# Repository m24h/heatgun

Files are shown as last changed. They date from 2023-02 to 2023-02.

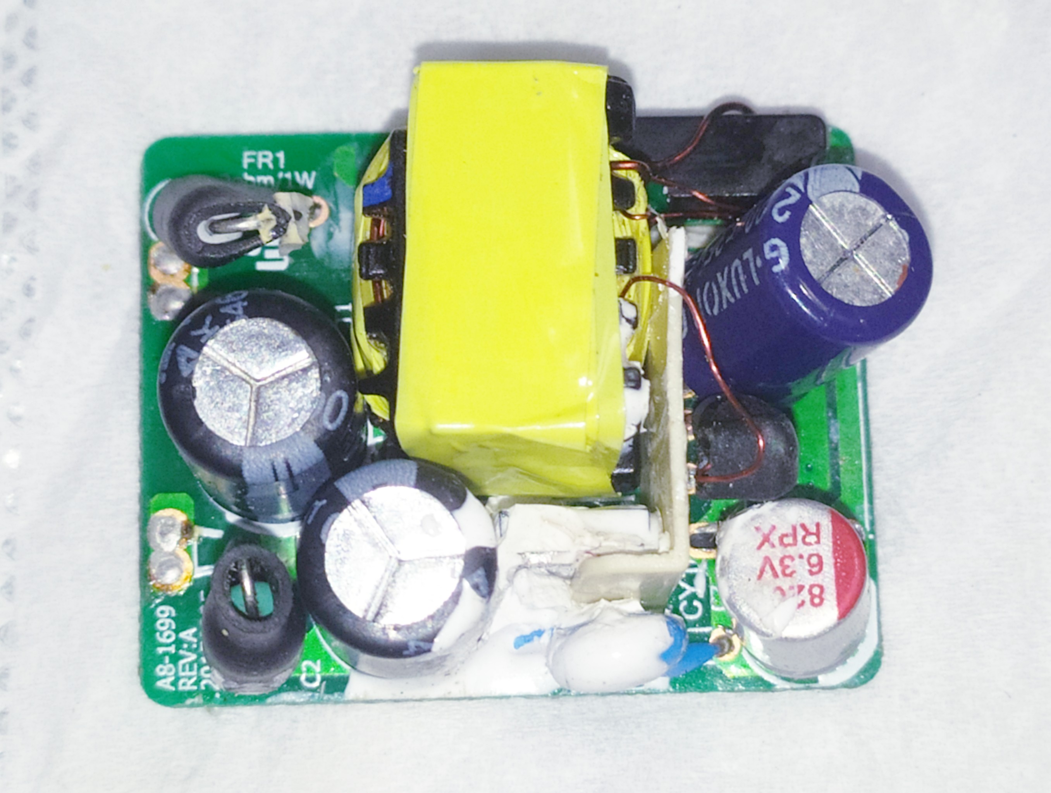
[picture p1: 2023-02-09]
practice/power-top.jpg

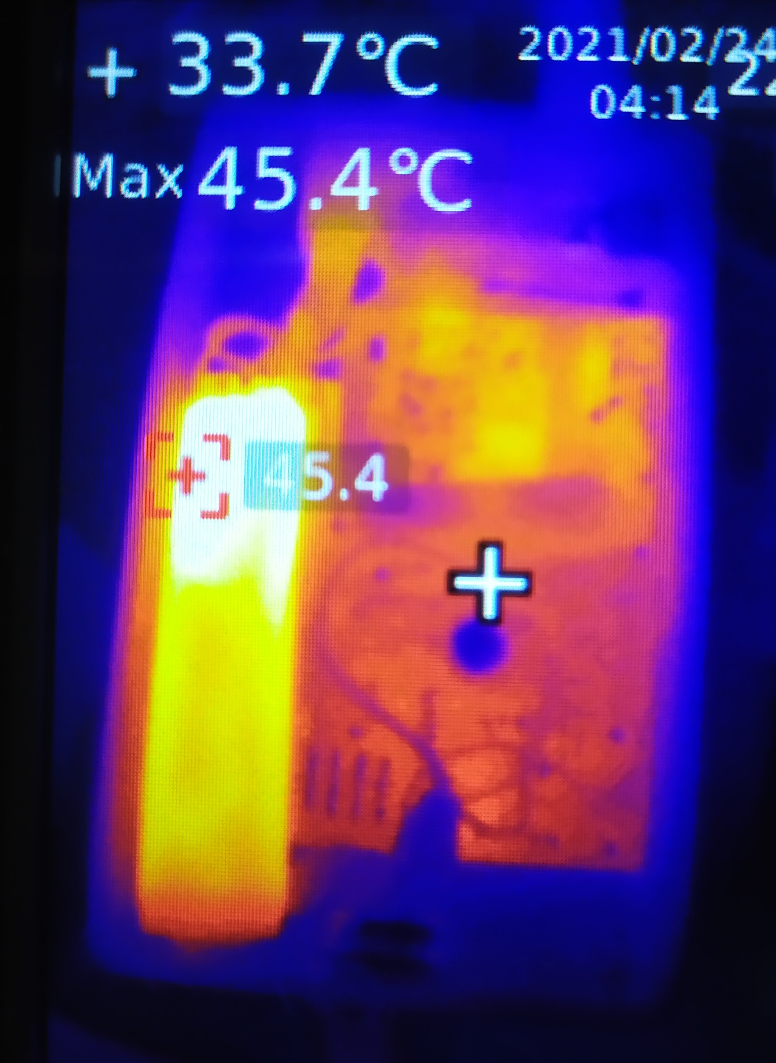
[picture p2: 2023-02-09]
practice/heat-sink.jpg

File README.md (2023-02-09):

# heatgun
A small hot air station for soldering, using type-858 heat gun as handle, STC8G1k17 as MCU, copper wire resistor for cold junction compensation.

##Features:

* Small, cheap, esay to make
* With cold junction compensation
* Software correction 
* Compatible with most type-858 handle
* Settings can be remembered
* PID temperature control

## Burning/Downloading

This program is only for MCU STC8G1K17-16pin, compiled and linked by SDCC 4.2.0

It must be burned at following scheme:

* Internal IRC Freq. : 22.1184MHz (as same as specified in def.h)
* User EEPROM size : 2k (as same as specified in def.h)
* Low-voltage reset : Enable
* Reset pin used as I/O port : Yes
* Hardware enable WDT : Disable (I will use software enable it)
* Add a reset code in front of ID : Yes (it will adds Band-Gap voltage reference)
* Erase all EEPROM data : Yes
* Fill data to space area : 0XFF

## About cold junction compensation for the thermocouple in the handle

I add a coper wire wound resistor (nearly 13.5 OHM) in the handle, in series with the thermocouple, for cold junction compensation at a suitable bias current.
And my software will do some corrections/calculations for getting accurate temperature from the thermocouple.

But if the connector between your handle and main controller board is not in good contact, this will introduce jitter in the temperature values.

In this case, the coper wire resistor can be totally removed, and several components (R5,R13) on the PCB can also be removed,
and several parameters inside the program can also be adjusted (set g_ana_pk=0 at main.c). 

In fact, the temperature rising of the thermocouple's cold junction within the handle, is not obvious. 
It is not really necessary to do cold junction compensation, and there are already an offset compensation. 
As long as you press and hold the button at startup, you can enter room temperature parameter.
In most cases, this is enough.

## About offset adjustment for AMP (LM321)

LM321 used in my circuit is not a precision OP-AMP and there may be large input offset voltage (normally within a few millivolts).
Because of the cold junction compensation circuit, its negative offset can be ignored, 
but if the positive offset is too large, it may be necessary to add resistor (R14) to the circuit for keeping the output in the linear range.

If you remove the cold junction compensation resistor in the handle, and the negative offset cannot be ignored, 
I suggest that you still need to add one resistor in series, however, this resistor can take a larger value, 
and at the same time increase the values of R5 and R13 in the circuit, 
so that there will be no obvious jitter caused by the connector contact resistor.

Also do not adjust the offset to 0, keep an output of OP-AMP hundreds of millivolts at least.

## About the gain of AMP (LM321)

LM321 is also not a rail-to-rail OP-AMP, especially since its high output is close to 1V away from the power voltage.

If the gain designed is too large, the temperature measurement range will be limited. 
With my current design, there is no problem with the range within 500 centidegrees, 
but if a larger range is needed, the gain needs to be reduced (change R8/R9) and the parameters (g_ana_gain at main.c) in program needs to be adjusted too.

## About power supply

The circuit requires 2 ways of power supply, a 5V for controller, another 24V for the fan (normally 24V 0.1xxA) in the handle.
I didn't include this in my design, you can use the finished product from other way, or modify an unused phone charger like me (10W required).

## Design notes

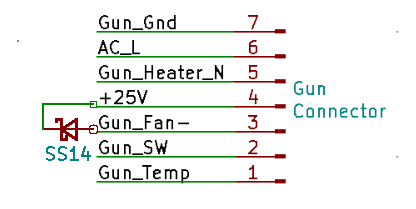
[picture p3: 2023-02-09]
circuit/gun_connector.png

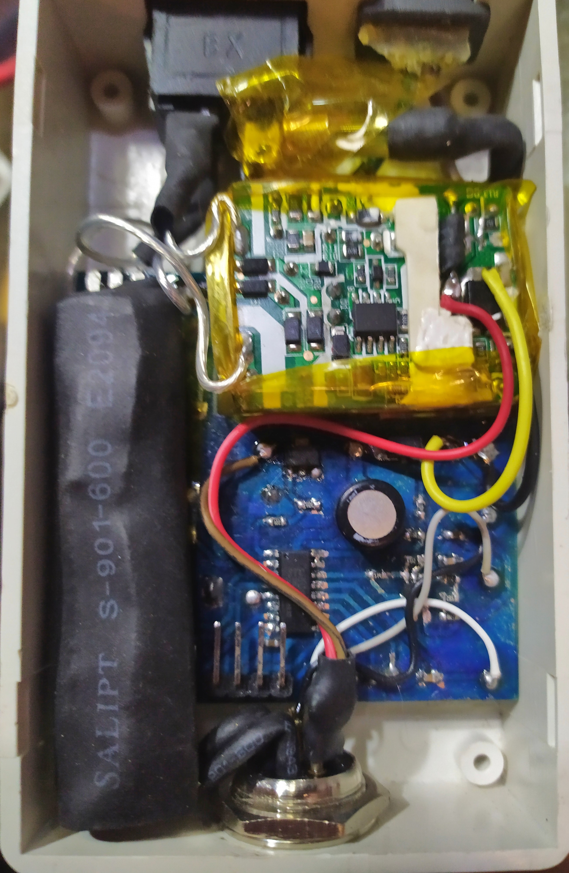
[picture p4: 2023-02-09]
practice/in-box.jpg

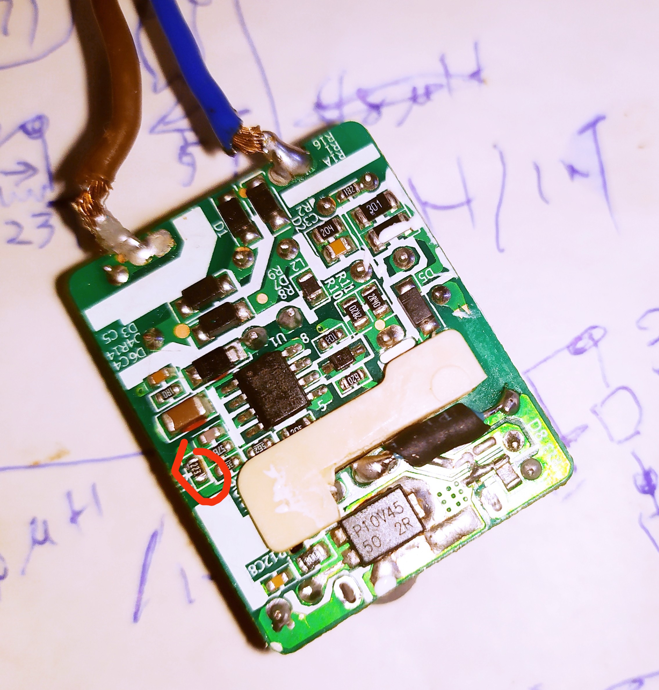
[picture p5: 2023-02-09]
practice/power-bottom.jpg

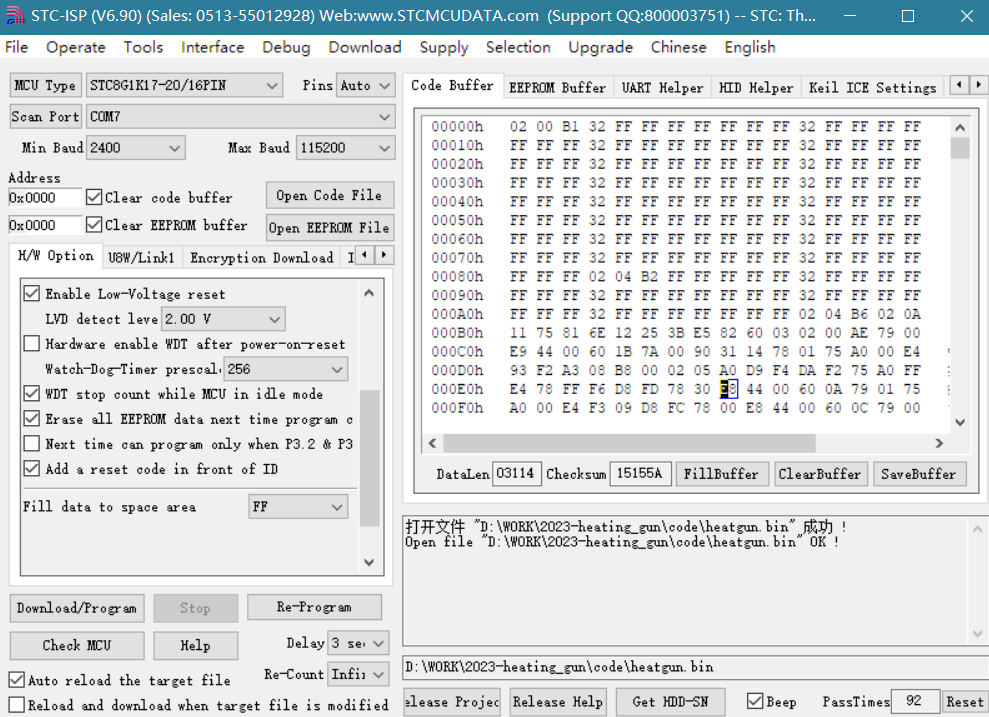
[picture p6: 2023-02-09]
practice/burn2.png

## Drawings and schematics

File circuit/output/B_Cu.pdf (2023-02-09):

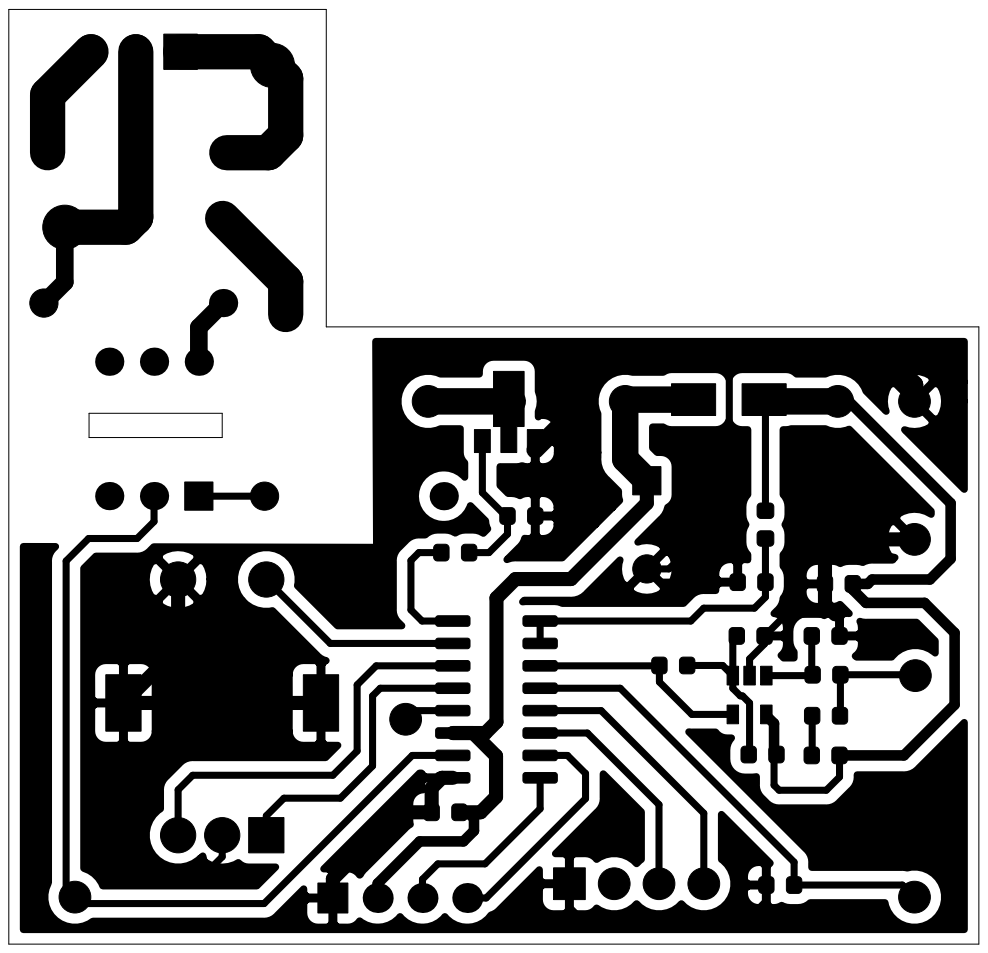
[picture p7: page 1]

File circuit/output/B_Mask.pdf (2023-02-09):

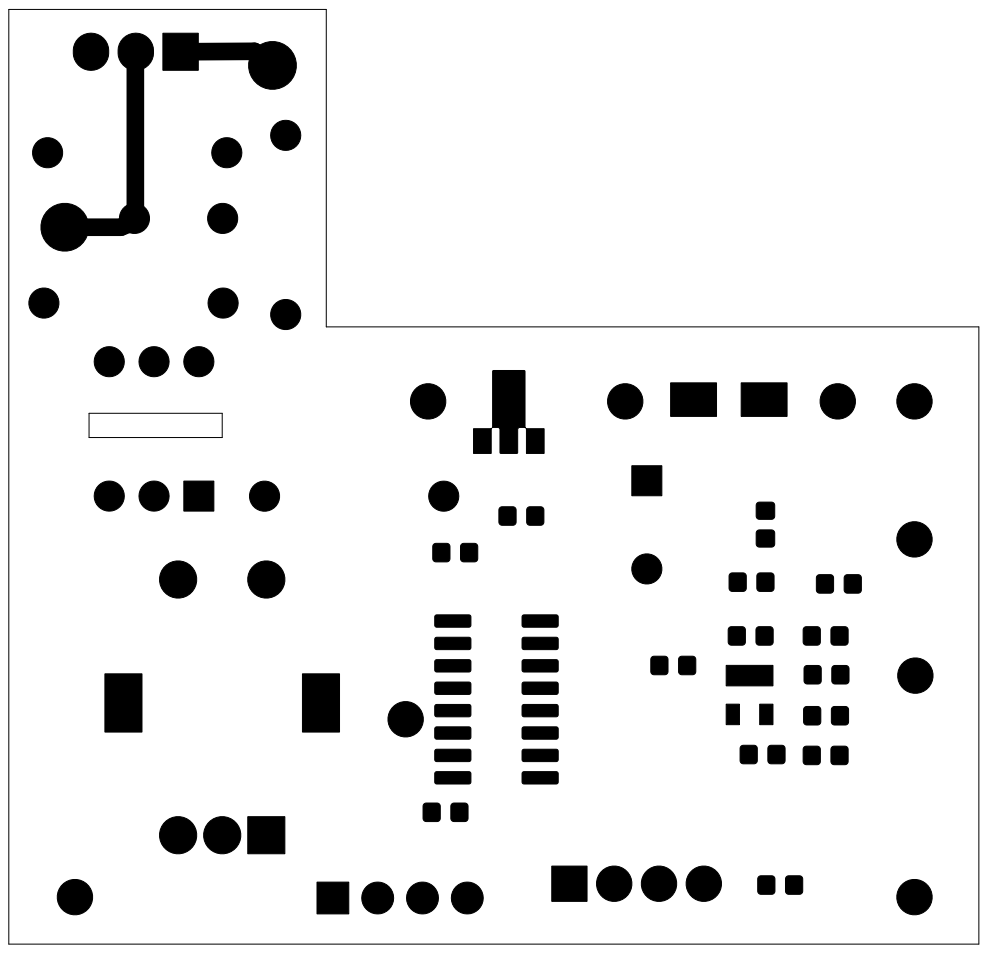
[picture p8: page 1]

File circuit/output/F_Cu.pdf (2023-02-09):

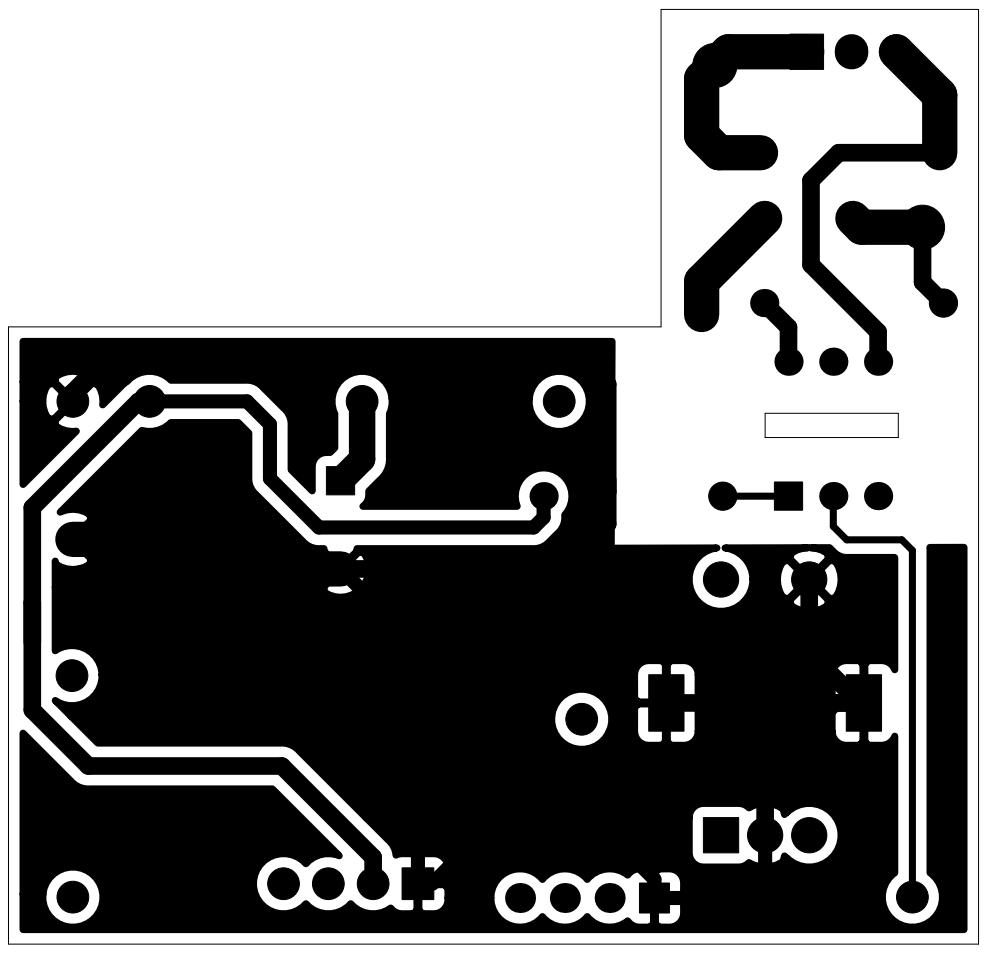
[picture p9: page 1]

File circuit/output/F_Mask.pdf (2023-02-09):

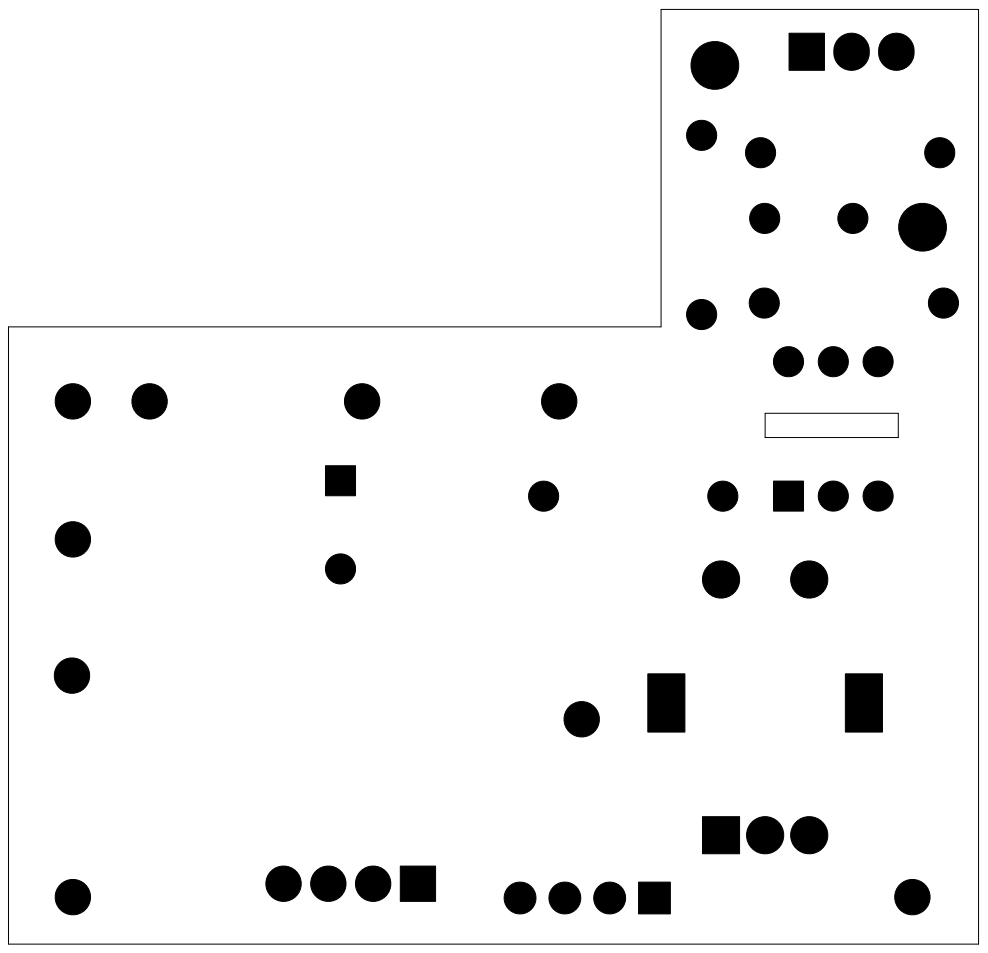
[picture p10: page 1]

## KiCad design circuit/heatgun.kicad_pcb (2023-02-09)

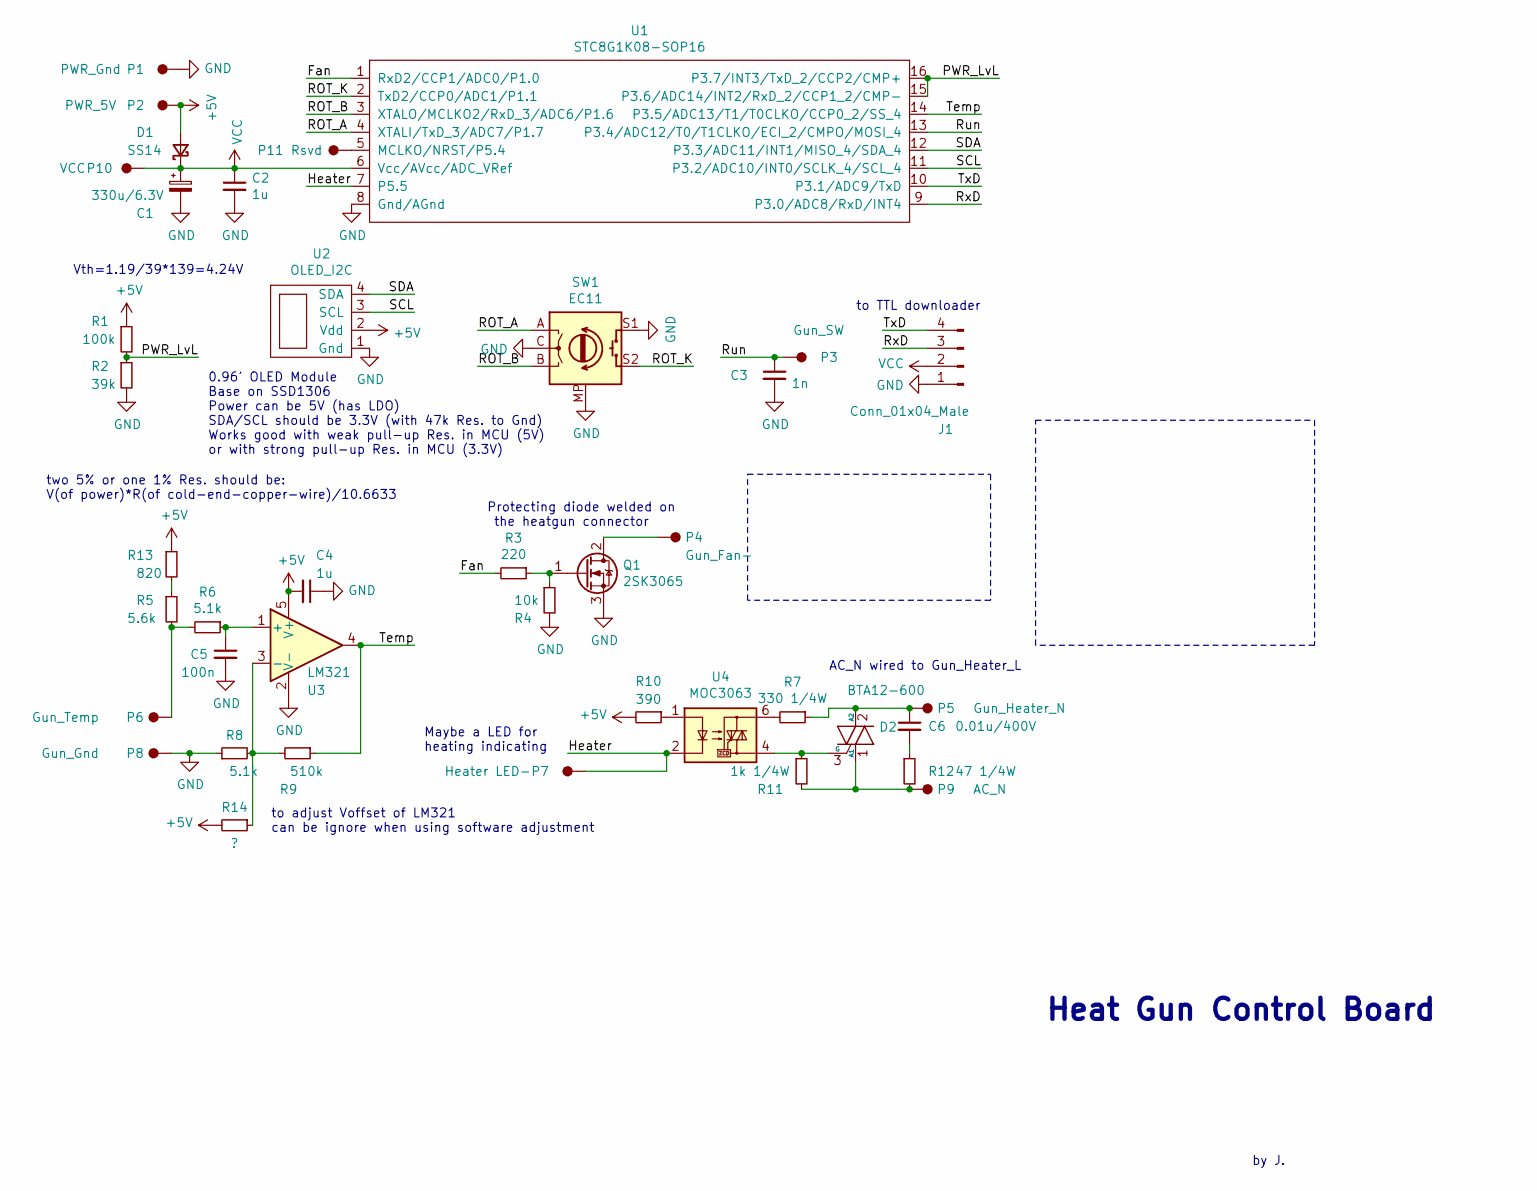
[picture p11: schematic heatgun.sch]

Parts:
C1: 330u/6.3V; CP_Radial_D8.0mm_P5.00mm
C2, C4: 1u; C_0603_1608Metric
C3: 1n; C_0603_1608Metric
C5: 100n; C_0603_1608Metric
C6: 0.01u/400V; C_Rect_L7.0mm_W2.5mm_P5.00mm
D1: SS14; D_SMA
D2: BTA12-600; TO-220-3_Vertical
J1: Conn_01x04_Male; PinHeader_1x04_P2.54mm_Vertical
P1: PWR_Gnd; Pad-1.8-h1
P2: PWR_5V; Pad-1.8-h1
P3: Gun_SW; Pad-1.8-h1
P4: Gun_Fan-; Pad-1.8-h1
P5: Gun_Heater_N; Pad-2.5-h1
P6: Gun_Temp; Pad-1.8-h1
P7: Heater LED-; Pad-1.8-h1
P8: Gun_Gnd; Pad-1.8-h1
P9: AC_N; Pad-2.5-h1
P10: VCC; Pad-1.8-h1
P11: Rsvd; Pad-1.8-h1
Q1: 2SK3065; SOT-89-3
R1: 100k; R_0603_1608Metric
R2: 39k; R_0603_1608Metric
R3: 220; R_0603_1608Metric
R4: 10k; R_0603_1608Metric
R5: 5.6k; R_0603_1608Metric
R6, R8: 5.1k; R_0603_1608Metric
R7: 330 1/4W; R_Axial_DIN0207_L6.3mm_D2.5mm_P10.16mm_Horizontal
R9: 510k; R_0603_1608Metric
R10: 390; R_Axial_DIN0207_L6.3mm_D2.5mm_P10.16mm_Horizontal
R11: 1k 1/4W; R_Axial_DIN0207_L6.3mm_D2.5mm_P10.16mm_Horizontal
R12: 47 1/4W; R_Axial_DIN0207_L6.3mm_D2.5mm_P10.16mm_Horizontal
R13: 820; R_0603_1608Metric
R14: ?; R_0603_1608Metric
SW1: EC11; RotaryEncoder_Alps_EC11E-Switch_Vertical_H20mm
U1: STC8G1K08-SOP16; SOIC-16_3.9x9.9mm_P1.27mm
U2: OLED_I2C; OLED-I2C-0.96-27.5X27.8
U3: LM321; SOT-23-5
U4: MOC3063; DIP-6_W7.62mm

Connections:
+5V: C4.2, D1.2 (A), P2.1, R1.1, R10.2, R13.1, R14.2, U2.2 (Vdd), U3.5 (V+)
/Fan: R3.2, U1.1 (RxD2/CCP1/ADC0/P1.0)
/Heater: P7.1, U1.7 (P5.5), U4.2
/PWR_LvL: R1.2, R2.1, U1.15 (P3.6/ADC14/INT2/RxD_2/CCP1_2/CMP-), U1.16 (P3.7/INT3/TxD_2/CCP2/CMP+)
/ROT_A: SW1.A, U1.4 (XTALI/TxD_3/ADC7/P1.7)
/ROT_B: SW1.B, U1.3 (XTALO/MCLKO2/RxD_3/ADC6/P1.6)
/ROT_K: SW1.S2, U1.2 (TxD2/CCP0/ADC1/P1.1)
/Run: C3.1, P3.1, U1.13 (P3.4/ADC12/T0/T1CLKO/ECI_2/CMPO/MOSI_4)
/RxD: J1.3, U1.9 (P3.0/ADC8/RxD/INT4)
/SCL: U1.11 (P3.2/ADC10/INT0/SCLK_4/SCL_4), U2.3 (SCL)
/SDA: U1.12 (P3.3/ADC11/INT1/MISO_4/SDA_4), U2.4 (SDA)
/Temp: R9.1, U1.14 (P3.5/ADC13/T1/T0CLKO/CCP0_2/SS_4), U3.4
/TxD: J1.4, U1.10 (P3.1/ADC9/TxD)
GND: C1.2, C2.2, C3.2, C4.1, C5.2, J1.1, P1.1, P8.1, Q1.3 (S), R2.2, R4.2, R8.1, SW1.C, SW1.MP, SW1.S1, U1.8 (Gnd/AGnd), U2.1 (Gnd), U3.2 (V-)
unnamed: C5.1, R6.1, U3.1 (+)
unnamed: C6.1, D2.2 (A2), P5.1, R7.1
unnamed: C6.2, R12.1
unnamed: D2.1 (A1), P9.1, R11.2, R12.2
unnamed: D2.3 (G), R11.1, U4.4
unnamed: P4.1, Q1.2 (D)
unnamed: P6.1, R5.2, R6.2
unnamed: P11.1, U1.5 (MCLKO/NRST/P5.4)
unnamed: Q1.1 (G), R3.1, R4.1
unnamed: R7.2, U4.6
unnamed: R10.1, U4.1
unnamed: R5.1, R13.2
unnamed: R8.2, R9.2, R14.1, U3.3 (-)
VCC: C1.1, C2.1, D1.1 (K), J1.2, P10.1, U1.6 (Vcc/AVcc/ADC_VRef)

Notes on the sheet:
Protecting diode welded on the heatgun connector
AC_N wired to Gun_Heater_L
to TTL downloader
0.96' OLED Module Base on SSD1306 Power can be 5V (has LDO) SDA/SCL should be 3.3V (with 47k Res. to Gnd) Works good with weak pull-up Res. in MCU (5V) or with strong pull-up Res. in MCU (3.3V)
Maybe a LED for heating indicating
Vth=1.19/39*139=4.24V
two 5% or one 1% Res. should be: V(of power)*R(of cold-end-copper-wire)/10.6633
to adjust Voffset of LM321 can be ignore when using software adjustment
Heat Gun Control Board
by J.

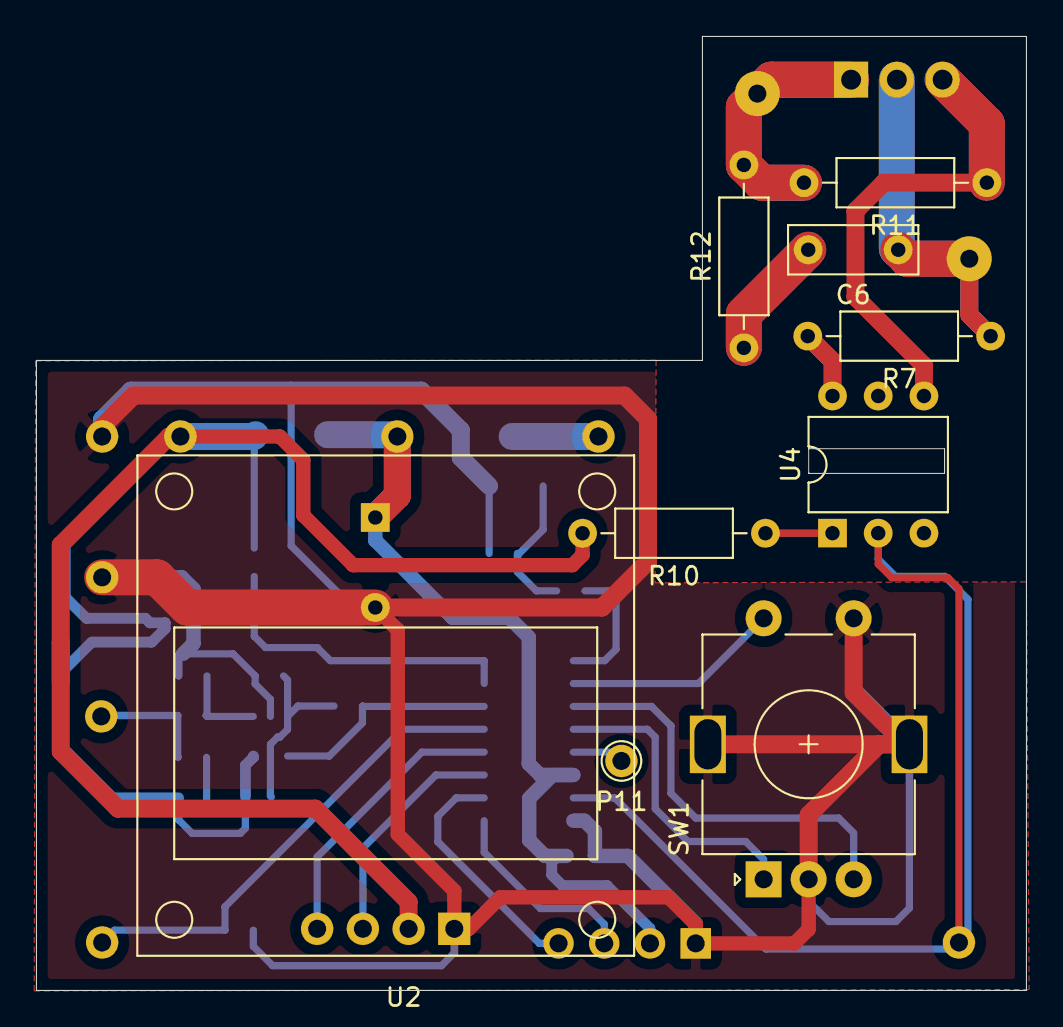
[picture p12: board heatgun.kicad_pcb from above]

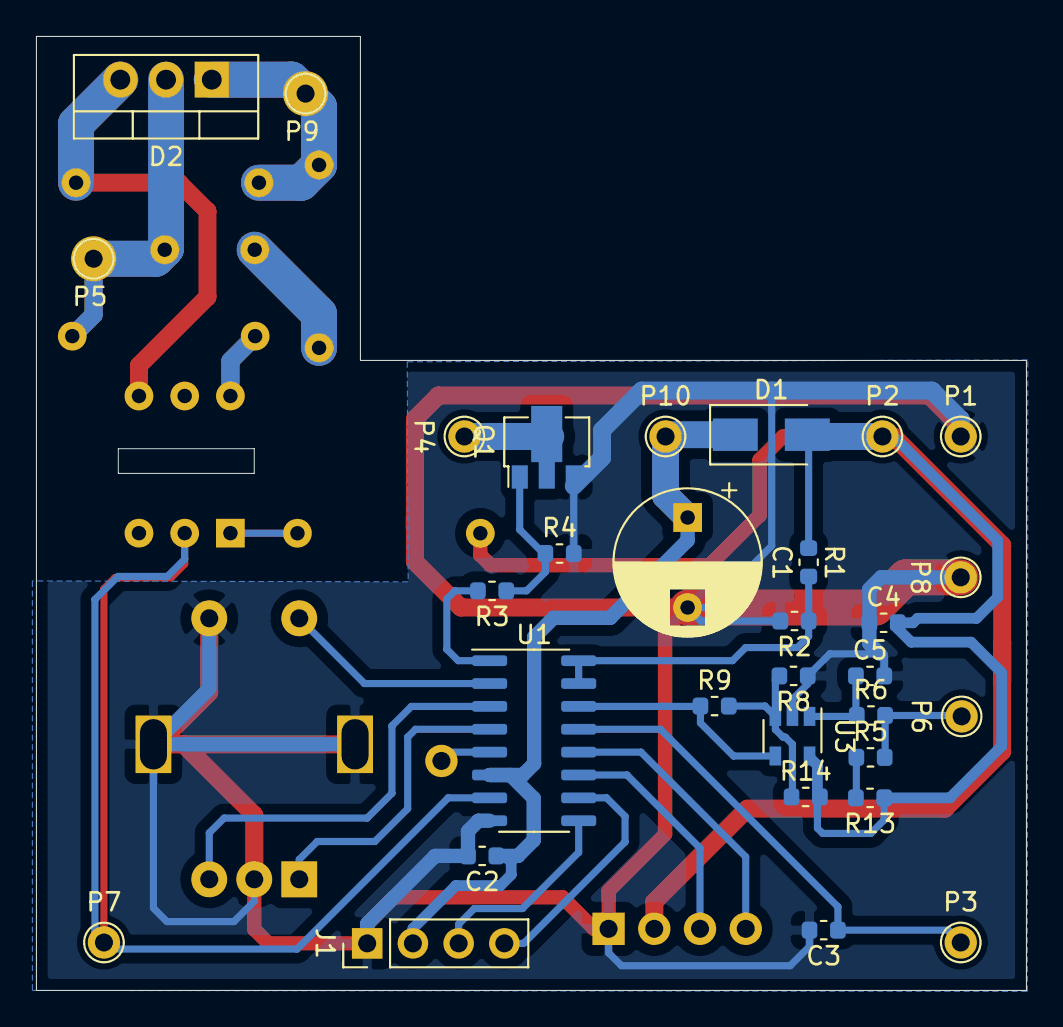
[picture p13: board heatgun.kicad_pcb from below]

Board: 2 copper layers, 55.0 x 53.0 mm, 40 parts (31 on the bottom side), 28 nets.

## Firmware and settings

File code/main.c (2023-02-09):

// Copyright 2003 m24h, see http://www.apache.org/licenses/LICENSE-2.0

#include	"def.h"
#include	"iic.h"
#include	"ssd1306.h"
#include      "ser.h"
#include	"fonts.h"
#include	"K.h"
#include	"key.h"
#include	"iap.h"
#include	"eeprom.h"
#include	"tools.h"

/*
	This program is for STC8G1K17-16pin
	MCU must be burned at following scheme:
		Internal IRC Freq. : 22.1184MHz (as same as specified in def.h)
		User EEPROM size : 2k (as same as specified in def.h)
		Low-voltage reset : Enable
		Reset pin used as I/O port : Yes
		Hardware enable WDT : Disable (I will use software enable it)
		Add a reset code in front of ID : Yes (it will adds Band-Gap voltage reference)
		Erase all EEPROM data : Yes
		Fill data to space area : 0XFF
	Calibration Data:
		They will be set at last flash page which is start from 0x4200 (or 0x600 at EEPROM address)
*/

#define DEBUG 1
#define TRACE  1

#define FREQ_IIC        200000   /* IIC frequency */
#define BAUDRATE     115200 /* serial baudrate */

#define TEMP_MIN  100  /* lowest temperature setting */
#define TEMP_MAX  500 /* highest temperature setting */
#define TEMP_COLD 25 /* init or default room temperature */
#define TEMP_TIMEOUT  10 /* in seconds,  if in temperature controlling mode, when timeout, it will be automatically back to blow controlling mode */
#define BLOW_LEVELS 16   /* levels of wind blowing control */
#define BLOW_PWM_MIN 50   /* 0-255 PWM setting when blowing setting level 0, this should be tested for another fan, don't make fan stop spinning  */
#define BLOW_STOP_TEMP 80 /* when temperature is cool-down to this, blowing can stop */
#define BLOW_START_TEMP 200 /* when temperature is higher than this, blowing must start to protect heating gun */

#define PID_KP	0.08  /* nearly 20 centigrades make full control */
#define PID_TI	200
#define PID_TD	8
#define PID_TF	2
#define PID_FALL	5   /* Enhance the control effect for temperature falling, which is always slower than rising */
#define PID_EDGE_TOP    4     /* use directly control instead of PID when temperature error is out of a range */
#define PID_EDGE_BTM   100     /* use directly control instead of PID when temperature error is out of a range */

#define ANA_GAIN 0.009901 /* gain of input to output of AMP 5.1k/(5.1k+510k), in design */
#define ANA_OFF   0.0              /* offset of AMP and residuals, in uV, 0 in design */
#define ANA_PK      0.002176  /* correction coefficient of power voltage, 14/(6420+14), in design */
#define ANA_PG     3.5641  /* gain of power voltage  to ADC input, (39+100)/39, in design */

// ADC Band-Gap reference
#define BG_REF_DEF	1190    /* default, will be used if loading from BG_REFL/BG_REFH fails */
__code __at(EEPROM_OFFSET+EEPROM_PAGE_SIZE*EEPROM_PAGES-8) u8 BG_REFL;  // get Band-Gap Ref. mV, need to enable "Add a reset code in front of ID" option before downloading using STC-ISP
__code __at(EEPROM_OFFSET+EEPROM_PAGE_SIZE*EEPROM_PAGES-9) u8 BG_REFH; // get Band-Gap Ref. mV, need to enable "Add a reset code in front of ID" option before downloading using STC-ISP

// my calibration data
__code __at(EEPROM_OFFSET+EEPROM_PAGE_SIZE*(EEPROM_PAGES-1)) 		u8 CALI_TAG;          // when CALI_XXX exists, it will be 0x55
__code __at(EEPROM_OFFSET+EEPROM_PAGE_SIZE*(EEPROM_PAGES-1)+2) 	u8 CALI_OFFSETH;  // add offset, in uV, signed
__code __at(EEPROM_OFFSET+EEPROM_PAGE_SIZE*(EEPROM_PAGES-1)+3)	u8 CALI_OFFSETL;   // add offset, in uV, signed
__code __at(EEPROM_OFFSET+EEPROM_PAGE_SIZE*(EEPROM_PAGES-1)+4) 	u8 CALI_GAINH;  // add AMP gain, in 1/32768, signed
__code __at(EEPROM_OFFSET+EEPROM_PAGE_SIZE*(EEPROM_PAGES-1)+5)	u8 CALI_GAINL;  // add AMP gain, in 1/32768, signed
__code __at(EEPROM_OFFSET+EEPROM_PAGE_SIZE*(EEPROM_PAGES-1)+6) 	u8 CALI_PKH;  // add correction coefficient of power voltage, in 1/32768, signed
__code __at(EEPROM_OFFSET+EEPROM_PAGE_SIZE*(EEPROM_PAGES-1)+7)	u8 CALI_PKL;   // add correction coefficient of power voltage, in 1/32768, signed
__code __at(EEPROM_OFFSET+EEPROM_PAGE_SIZE*(EEPROM_PAGES-1)+8) 	u8 CALI_PGH;  // add gain of power voltage  to ADC input, in 1/32768, signed
__code __at(EEPROM_OFFSET+EEPROM_PAGE_SIZE*(EEPROM_PAGES-1)+9)	u8 CALI_PGL;    // add gain of power voltage  to ADC input, in 1/32768, signed

// global parametes and states
__pdata u16  	g_tick=0; // timer tick value

//__pdata float 	g_ana_gain       =ANA_GAIN;    
__pdata float 	g_ana_gain       =0.009980;    // gain of input to output of AMP 5.02k/(5.02k+498k), measured, 0.009901 is designed value
//__pdata float 	g_ana_off          =ANA_OFF;   
__pdata float 	g_ana_off          =2750;            // offset of AMP and residuals, in uV, measured
//__pdata float	g_ana_pk          = ANA_PK;   
__pdata float	g_ana_pk          = 0.00231;      // correction coefficient of power voltage,  measured , 0.002176  is designed value
__pdata float	g_ana_pg          = ANA_PG; 

__pdata u16	g_eeprom_addr=0;  // address for read/write config in eeprom
__pdata u16	g_temp_set_load=0;  // temperature setting, loaded from eeprom
__pdata u8		g_blow_load=0;  // temperature setting, loaded from eeprom

__pdata u16  	g_vref_bg=BG_REF_DEF;      // ADC Band-Gap Vref., in mV
__pdata u16  	g_adc_vref=0;    // ADC raw value of Band-Gap Vref
__pdata u16  	g_adc_pwr=0;    // ADC raw value of power (not Vcc of STC8G), and it's divided by 39k/(100k+39k) resistor net
__pdata u16	g_adc_temp=0; // ADC raw value of temperature

__pdata u16	g_temp_set=(TEMP_MAX+TEMP_MIN)/2;  // temperature setting, TEMP_MIN - TEMP_MAX
__pdata u8         g_blow=BLOW_LEVELS/2;     // blowing rate  0-(BLOW_LEVELS-1)  (0 means PWM output BLOW_PWM_MIN )

__bit			g_cali_mode=0;  // 1: in calibration mode
__pdata u8		g_cali_temp=TEMP_COLD;   // calibration room temperature
__bit			g_work=0;      // 1: system working 0: not work, whatever if g_run is 0 or 1
__bit 			g_run=0;            // 1: blowgun is working (switch is off)
__pdata u16	g_temp_cur=TEMP_COLD<<5;  // current measured temperature, 5-bit fixed point
__pdata u16	g_vcc=VCC;  // power Vcc voltage, in mV
__bit			g_blowing=0;  //1: currently blowing
__bit			g_heating=0; //1: currently heating

__bit 			g_rot_temp=0;  // 1: rotary encoder control temperature 0: rotary encoder control blowing
__pdata u8		g_rot_temp_timeout=0;  // 0:timeout
__bit			g_flicker=0;   // for display flicker, toggled by timer

// events
__bit e_key_button=0;     // need to check rotary encoder button
__bit e_key_rot=0;     // need to check rotary encoder step pulses
__bit e_key_run=0;     // need to check gun's switch
__bit e_disp_flush=0;     // need to flush display
__bit e_adc_vref=0;  // need to sample ADC channels
__bit e_adc_pwr=0;  // need to sample ADC channels
__bit e_adc_temp=0;  // need to sample ADC channels
__bit e_fan_control=0;  // need to control fan PWM
__bit e_heat_control=0; // need to control heating
__bit e_calc=0; // need to calculate temperature and do heating control


// save back calibrated data
void factory_save()
{
	__xdata u8 p[EEPROM_PAGE_SIZE];
	i16 t;
	iap_load (p, EEPROM_PAGES-1);
	p[0]=0x55;
	t=(i16)(g_ana_off-ANA_OFF);
	p[2]=t>>8;
	p[3]=(u8)t;
	t=(i16)((g_ana_gain/ANA_GAIN-1.0)*32768+0.5);
	p[4]=t>>8;
	p[5]=(u8)t;
	t=(i16)((g_ana_pk/ANA_PK-1.0)*32768+0.5);
	p[6]=t>>8;
	p[7]=(u8)t;
	t=(i16)((g_ana_pg/ANA_PG-1.0)*32768+0.5);
	p[8]=t>>8;
	p[9]=(u8)t;
	iap_save (p, EEPROM_PAGES-1);	
#if DEBUG
	ser_str("Cali data saved\r\n");
#endif
}

// read ADC ch , ch==0x0f means internal Gap-Band voltage, output 0~65535
#pragma callee_saves adc_read
u16 adc_read(u8 ch)
{
	ADC_CONTR =ch | 0b11000000; // power on, start, select internal Gap-Band channel
	_nop();
	_nop();
	while (!(ADC_CONTR & 0b00100000));   // wait completing
	ADC_CONTR &= 0b11011111; // clear ADC_FLAG
	return ADC_RES16;  // optimized by using __sfr16
}

// change FAN PWM output, 0-0xFF, 0 means off, 0xFF means full power
#pragma callee_saves fan_ctrl
void fan_ctrl (u8 pwm)
{
	if (pwm)
		PCA_PWM1 &= 0b11001101;
	else
		PCA_PWM1 |= 0b00110010;

	CCAP1H = (u8)0xFF - pwm;
}

// if P3.0 is low, reboot for downloading
void on_P30_down()  __interrupt (16)
{
	IAP_CONTR = 0x60;
}

// when power is down
void on_cmp()   __interrupt (21)
{
	CMPCR1 &= 0b10111111; // clear flag 
	
	EA=0;
	CR=0; // stop PCA/PWM for saving power (maybe blow is stop/full power for a short time)
	if (g_temp_set_load!=g_temp_set || g_blow_load!=g_blow) { // need to save config
		iap_write(g_eeprom_addr, g_temp_set>>8);
		iap_write(g_eeprom_addr+1, g_temp_set);
		iap_write(g_eeprom_addr+2, g_blow);
		g_eeprom_addr=eeprom_save(g_eeprom_addr,3,0,EEPROM_PAGES-1);
		g_temp_set_load=g_temp_set;
		g_blow_load=g_blow;
#if DEBUG
		ser_str("config saved\r\n");
#endif
	} 
	CR=1;
	EA=1;

#if DEBUG
	ser_str("power lost\r\n");
#endif
}

// make digital array of a number for display
void digitalize (u16 u, __idata u8* p)
{
	p[2]=u%10;
	u-=p[2];
	u/=10;
	p[1]=u%10;
	u-=p[1];
	u/=10;
	p[0]=u%10;
}

// show string in display
/*
void disp_str(char * str, u8 col, u8 page)
{
	while (*str) {
		ssd1306_bitmap(col,page,8,16,FONTS_ASCII_8X16[*str-' ']);
		col+=8;
		str++;
	}
}
*/

// flush display
void disp_flush()
{
	static __bit cali_mode=0;	
	static __bit show_fixed=0;
	static __bit temp_flicker=0;
	static __bit heating=0;
	static __bit blowing=0;
	static __bit work=0;
	static __bit run=0;
	static __pdata u16 temp_set=0xffff;
	static __pdata u16 temp_cur=0xffff;
	static __pdata u8   blow=0xff;
	static __pdata u8   cali_temp=0xff;
	
	__idata u8 p[3];
	
	if (!(CMPCR1&0x01))  // maybe no power, just testing/downloading
		return;
		
	if (cali_mode!=g_cali_mode) {
		cali_mode=g_cali_mode;
		show_fixed=0;
		ssd1306_rect(0,0,128,8,0); // clear screen
	}
	
	if (cali_mode) {
		if (!show_fixed || cali_temp!=g_cali_temp) {
			cali_temp=g_cali_temp;
			digitalize(cali_temp, p);
			if (!p[0])
				ssd1306_rect(60,5,16,3,0);
			else 
				ssd1306_bitmap(60,5,16,3,FONTS_DIGI_SET_16X24[p[0]]);
			if (!p[0]  && !p[1])
				ssd1306_rect(76,5,16,3,0);
			else 
				ssd1306_bitmap(76,5,16,3,FONTS_DIGI_SET_16X24[p[1]]);
			ssd1306_bitmap(92,5,16,3,FONTS_DIGI_SET_16X24[p[2]]);
		}
	} else {
		// temperature "set" string flicker
		if (g_rot_temp) {
			if (!show_fixed || temp_flicker!=g_flicker) {
				temp_flicker=g_flicker;
				if (temp_flicker) {
					ssd1306_bitmap(0,0,16,3,FONTS_DIGI_SET_16X24[10]);  //S
					ssd1306_bitmap(16,0,16,3,FONTS_DIGI_SET_16X24[11]);  //E
					ssd1306_bitmap(32,0,16,3,FONTS_DIGI_SET_16X24[12]);  //T
					ssd1306_bitmap(48,0,11,3,FONTS_COLON_11X24);  //:
				} else {
					ssd1306_rect(0,0,59,3,0);
				}
			}
		} else {
			if (!show_fixed || !temp_flicker) {
				ssd1306_bitmap(0,0,16,3,FONTS_DIGI_SET_16X24[10]);  //S
				ssd1306_bitmap(16,0,16,3,FONTS_DIGI_SET_16X24[11]);  //E
				ssd1306_bitmap(32,0,16,3,FONTS_DIGI_SET_16X24[12]);  //T
				ssd1306_bitmap(48,0,11,3,FONTS_COLON_11X24);  //:
				temp_flicker=1;
			} 
		} 

		// show temperature setting number
		if (!show_fixed || temp_set!=g_temp_set) {
			temp_set=g_temp_set;
			digitalize(temp_set, p);
			if (!p[0])
				ssd1306_rect(60,0,16,3,0);
			else 
				ssd1306_bitmap(60,0,16,3,FONTS_DIGI_SET_16X24[p[0]]);
			if (!p[0]  && !p[1])
				ssd1306_rect(76,0,16,3,0);
			else 
				ssd1306_bitmap(76,0,16,3,FONTS_DIGI_SET_16X24[p[1]]);
			ssd1306_bitmap(92,0,16,3,FONTS_DIGI_SET_16X24[p[2]]);
		}

		if (!show_fixed || temp_cur!=((g_temp_cur+3)>>5)) {
			temp_cur=(g_temp_cur+3)>>5;
			digitalize(temp_cur, p);
			if (!p[0])
				ssd1306_rect(44,3,20,4,0);
			else 
				ssd1306_bitmap(44,3,20,4,FONTS_DIGI_20X32[p[0]]);
			if (!p[0]  && !p[1])
				ssd1306_rect(64,3,20,4,0);
			else 
				ssd1306_bitmap(64,3,20,4,FONTS_DIGI_20X32[p[1]]);
			ssd1306_bitmap(84,3,20,4,FONTS_DIGI_20X32[p[2]]);
		}

		if (!show_fixed || blow!=g_blow) {
			blow=g_blow;
			u8 t=1+(u8)((u16)blow*126/(BLOW_LEVELS-1));
			ssd1306_rect(0,7,t,1,0b01111111);
			if (t<127)
				ssd1306_rect(t,7,127-t,1,0b01000001);
			ssd1306_rect(127,7,1,1,0b01111111);
		}
		
		if (!show_fixed || heating!=g_heating || blowing!=g_blowing || work!=g_work || run!=g_run) {
			heating=g_heating;
			blowing=g_blowing;
			work=g_work;
			run=g_run;
			if (heating)
				ssd1306_bitmap(0,3,32,4,FONTS_HEAT_32X32);
			else if (work) {
				if (run)
					ssd1306_bitmap(0,3,32,4,FONTS_RUN_32X32);
				else
					ssd1306_bitmap(0,3,32,4,FONTS_WORK_32X32);
			} else if (blowing)
				ssd1306_bitmap(0,3,32,4,FONTS_BLOW_32X32);	
			else
				ssd1306_rect(0,3,32,4,0);
		}
	}
	
	if (!show_fixed) {
		show_fixed=1;
		if (cali_mode)
			ssd1306_bitmap(0,0,128,4,FONTS_CALI_128X32);  // calibration notice text
		else {
			ssd1306_bitmap(108,0,20,3,FONTS_CDG_20X24);  // centigrade
			ssd1306_bitmap(104,3,24,4,FONTS_CDG_24X32);  // centigrade
		}
	}	
}

// prog entry
void main()
{
	// disable intr. 
	EA=0;  
	
	// P0,P2,P4 is not used, all High-Z
	P0M0 = 0x00;
	P0M1 = 0xff;
	P2M0 = 0x00;
	P2M1 = 0xff;
	P4M0 = 0x00;
	P4M1 = 0xff;
	// P1.1 P1.6 P1.7:Rotary encoder input (0-Active, Weak-Pull-Up), P1.0:Fan output (1-Active, Push-Pull), others:High-Z
	P1 = 0b11000010;
	P1M0 = 0b00000001;
	P1M1 = 0b00111100;
	P1DR = 0b11111110; // enhance P1.0 output current
	P1SR = 0b11111110; // enhance P1.0 output rate
	// P3.5: Analog input, but want to enhance LM321 output range (weak pull-up),  P3.6 P3.7:Analog input (High-Z),
	// P3.4:Gun Swith input (1-Active), OC, pull-up only when scanning
	// P3.2 P3.3:IIC (Bi-Dir, 0-Active), P3.1 P3.0:Serial Port (Bi-Dir, 0-Start)
	P3 = 0b00001111;
	P3M0 = 0b00010000;
	P3M1 = 0b11110000;
	P3IE = 0b00011111; // disable digital mode for analog input
#if VCC<3800
	P3PU = 0b00001100; // will be used if power voltage is below 3.8V for more pull-up 
#endif
	//P5.5:Heating Control ouput (0-Active, OC), others:High-Z
	P5 = 0b00100000;
	P5M0 = 0b00100000;
	P5M1=0b11111111;
	P5DR = 0b11011111;  // enhance P5.5 output current
	
	// TxD=>P3.1 RxD=>P3.0 CCP1=>P1.0 
	P_SW1 &= 0b00001111;
	// enable XFR always (in fact, not so many RAM), SCL=>P3.2, SDA=>P3.3
	P_SW2 |= 0b10110000; 
	
	// init send-only serial 1 (using timer 2) for debug
	ser_init(65536 - FOSC/BAUDRATE/4);
#if DEBUG
	ser_str("start\r\n");
#endif
		
	// init I2C as master
	iic_init(((FOSC/2/FREQ_IIC)-4)/2);
#if DEBUG
	ser_str("init IIC done\r\n");
#endif
	
	// init ADC
	ADCCFG &= 0b11010000;  // result is left-alignment (a fake 16bit result), ADCclk=SYSclk/2/1
	ADCTIM = 0b10111111;  // 2(setup)+32(duty)+2(hold)+10(convert)=46 ADCclk 
	ADC_CONTR = 0b10001111;  // power on, stop, select internal Gap-Band channel 
	EADC = 0; // not use intro.
#if DEBUG
	ser_str("init ADC done\r\n");
#endif
	
	// init PCA1:8 bit PWM
	CCON &= 0b00111000; // not start now
	CMOD = CMOD & 0b01110000 | 0b00001010; // PCA use FOSC/4=5529.6kHz as clock, no overflow intr.
	CL = 0;  // counter start from 0
	CH = 0;
	CCAP1L = 0xFF; 
	CCAP1H = 0xFF;
	PCA_PWM1 = 0b00111111; // 8 bits PWM mode (FOSC/4/256=21.6kHz), start at 0-Level
	CCAPM1 = CCAPM1 & 0b10000000 | 0b01000010; // PWM mode
	CR = 1;  // start PCA
#if DEBUG
	ser_str("init PWM done\r\n");
#endif

	// init comparator 
	CMPCR1 = 0b10000001; // enable, no intr. , no output, P3.7 vs BandGap voltage
	CMPCR2 = 0b00111111; // enable analog filter and maxium digital filter
	tools_delay_ms(10); // wait for stable result
	IP2 |= 0b00100000;
	IP2H |= 0b00100000; // highest intr. priority
	CMPCR1 |= 0b00010000; // enable intr. when P3.7<BandGap
#if DEBUG
	ser_str("init CMP done\r\n");
#endif

	// init OLED
	if (CMPCR1&0x01) { // maybe no power, factory testing, oled will block IIC communication
		ssd1306_dev(SSD1306_ADDR1);
		ssd1306_init(0, 0, 0);
#if DEBUG
		ser_str("init OLED done\r\n");
#endif
	}

	// init global parameters
	_mk_u16(&g_vref_bg, BG_REFH, BG_REFL); //load band-gap vref
	if (g_vref_bg<(BG_REF_DEF-300) || g_vref_bg>(BG_REF_DEF+300)) // probably incorrect
		g_vref_bg=BG_REF_DEF;
#if DEBUG
	ser_str("Band-Gap Vref = ");
	ser_u32(g_vref_bg);
	ser_str(" mV\r\n");
#endif

	g_adc_vref=adc_read(15);
	g_adc_pwr=adc_read(14);
	g_adc_temp=adc_read(13);
	
	// calibration
	if (CALI_TAG==0x55) {
		i16 t;
		_mk_u16(&t, CALI_OFFSETH, CALI_OFFSETL);
#if DEBUG
		ser_str("Cali offset += ");
		ser_i32(t);
		ser_str(" uV\r\n");
#endif
		g_ana_off=(float)(ANA_OFF)+t;

		_mk_u16(&t, CALI_GAINH, CALI_GAINL);
#if DEBUG
		ser_str("Cali gain += ");
		ser_i32(t);
		ser_str(" /32768\r\n");
#endif
		g_ana_gain=(float)(ANA_GAIN)*(1.0+(float)t/32768);

		_mk_u16(&t, CALI_PKH, CALI_PKL);
#if DEBUG
		ser_str("Cali Pwr Coef += ");
		ser_i32(t);
		ser_str(" /32768\r\n");
#endif
		g_ana_pk=(float)(ANA_PK)*(1.0+(float)t/32768);

		_mk_u16(&t, CALI_PGH, CALI_PGL);
#if DEBUG
		ser_str("Cali Pwr gain += ");
		ser_i32(t);
		ser_str(" /32768\r\n");
#endif
		g_ana_pg=(float)(ANA_PG)*(1.0+(float)t/32768);
	} else {   // save first data
		factory_save();	
	}

	// load config from eeprom	
	g_eeprom_addr=eeprom_load(3, 0, EEPROM_PAGES-1); // the last page cannot be used, it contains some MCU setting
	if (g_eeprom_addr==0xFFFF) { // not found
#if DEBUG
		ser_str("Cfg not found\r\n");
#endif				
		g_temp_set=(TEMP_MIN+TEMP_MAX)/2;  
		g_blow=BLOW_LEVELS/2;  	
	} else {
#if DEBUG
		ser_str("Cfg found at 0x");
		ser_h16(g_eeprom_addr);
		ser_str("\r\n");
#endif		
		g_temp_set=g_temp_set_load=((u16)iap_read(g_eeprom_addr)<<8)+iap_read(g_eeprom_addr+1);
		g_blow=g_blow_load=iap_read(g_eeprom_addr+2);
		if (g_temp_set<TEMP_MIN)
			g_temp_set=TEMP_MIN;
		else if (g_temp_set>TEMP_MAX)
			g_temp_set=TEMP_MAX;
		if (g_blow>=BLOW_LEVELS)
			g_blow=BLOW_LEVELS-1;
	}
	
	// prepare for saving eeprom
	g_eeprom_addr=eeprom_save(g_eeprom_addr,3,0,3);
#if DEBUG
		ser_str("next Cfg at 0x");
		ser_h16(g_eeprom_addr);
		ser_str("\r\n");
#endif		
	
	// init timer 1, frequency is 1000Hz
	ET1=0; // no intr.
	TCON &= 0b00111111;  // stop T1
	INTCLKO &= 0b11111101; // T1 no clock port output	
	TMOD &= 0b00001111;  // 16bit auto-reload mode for T1
	TL1 = (u8)(65536UL-FOSC/12/1000); 
	TH1 = (u8)((65536UL-FOSC/12/1000)>>8); 
	AUXR &= 0b10111111;  // T1 use FOSC/12
#if DEBUG
	ser_str("init Timer1 done\r\n");
#endif

	// enable P3.0 fall-down intr. to reboot
	INTCLKO |= 0b01000000;
	
	// check if enter calibration mode
	if (!P11) {
		g_cali_mode=1;
#if DEBUG
		ser_str("enter calibration mode\r\n");
#endif
	}

	// enable watch dog
	WDT_CONTR = 0b00110101; // nearly 1.2s
	
	// start timer
 	TR1 = 1;

	// enable all intr.
	EA = 1;

	// main loop, try to do only one thing one time
	while(1) {
		// clear watch dog
		WDT_CONTR |=0b00010000;
			
		// heating control
		if (e_heat_control) {
			e_heat_control=0;
			// pid control, anti-integral-windup
			// G(s)=kp(e+e/(ti*S)+td*S*e/(1+Tf*S))
			static float ei=0;
			static float ed=0;
			static u16 last_temp_cur=TEMP_COLD<<5;
			static u16 last_temp_set=0;
			ed=(ed*PID_TF+(float)(i16)(last_temp_cur-g_temp_cur)/32.0)/(1+PID_TF);
			if (g_run && g_work) {
				float e=(float)g_temp_set-(float)g_temp_cur/32.0;
				if (last_temp_set!=g_temp_set)
					ei=0.0;
				if (e>PID_EDGE_BTM) {
					g_heating=1;
					ei=0;					
				} else if (e<-PID_EDGE_TOP) {
					g_heating=0;
					ei=0;
				} else {
					float y=e<0.0?e*(PID_FALL):e;
					y+=(ei+e)/(PID_TI);
					y+=(ed<0.0?ed*(PID_FALL):ed)*(PID_TD);
					y*=(PID_KP);
					if (e>0 && y<1.0 || e<0 && y>-1.0)
						ei+=e;
					g_heating=(y>1.0);
				}
			} else {
				ei=0;
				ed=0;
				g_heating=0;
			}
			last_temp_cur=g_temp_cur;
			last_temp_set=g_temp_set;
			P55=g_heating?0:1;
			continue;
		}
		
		// fan control	
		if (e_fan_control) {
			e_fan_control=0;
			if ((g_run && g_work)
			    || g_temp_cur>=(BLOW_START_TEMP<<5)
			    || (g_temp_cur>=(BLOW_STOP_TEMP<<5)  && g_blowing) // hysteretic control
			) {  
				g_blowing=1;
				fan_ctrl(BLOW_PWM_MIN+(u8)(((255-BLOW_PWM_MIN)*g_blow+(BLOW_LEVELS-2))/(BLOW_LEVELS-1))); 
			} else {
				g_blowing=0;
				fan_ctrl(0);
			}
			continue;
		}

		// ADC control
		if (!(ADC_CONTR & 0b01100000)) { // ADC not working
			if (e_adc_vref) {
				e_adc_vref=0;
				ADC_CONTR =15 | 0b11000000;
				continue;
			} else if (e_adc_pwr) {
				e_adc_pwr=0;
				ADC_CONTR =14 | 0b11000000;
				continue;
			} else if (e_adc_temp) {
				e_adc_temp=0;
				ADC_CONTR =13 | 0b11000000;
				continue;
			}
		} else if (ADC_CONTR & 0b00100000) { // done
			ADC_CONTR &= 0b10001111; // clear ADC_FLAG
			u8 ch=ADC_CONTR & 0b00001111;
			if (ch==15)
				g_adc_vref+= ((i16)(ADC_RES16-g_adc_vref)>>3);  // simple filter, for ADC_RES16 is in fact 10 bits significant
			else if (ch==14)
				g_adc_pwr+= ((i16)(ADC_RES16-g_adc_pwr)>>3);  // simple filter, for ADC_RES16 is in fact 10 bits significant
			else if (ch==13)
				g_adc_temp+= ((i16)(ADC_RES16-g_adc_temp)>>3);  // simple filter, for ADC_RES16 is in fact 10 bits significant
			continue;
		}
		
		// calculate temperature
		if (e_calc) {
			e_calc=0;
			
			float k_ref=1000.0*g_vref_bg/g_adc_vref;  
			float v_pwr=k_ref*g_adc_pwr*g_ana_pg;      // in uV
			g_vcc=(u16)(v_pwr/1000+0.5);
			float v_temp=k_ref*g_adc_temp*g_ana_gain-v_pwr*g_ana_pk+g_ana_off; // in uV
			
			if (v_temp<0.0) 
				v_temp=0.0;
			else if (v_temp>60000.0) 
				v_temp=60000.0;
			
			u16 temp=K_temp((u16)(v_temp+0.5));
			if (temp!=0xFFFF) 
				g_temp_cur+=(i16)(temp-g_temp_cur)>>2; // a simple filter, round-off error is acceptable (1/8 centidegree)

			continue;
		}
			
		// rotary pulses
		if (e_key_rot) { // 500Hz
			e_key_rot=0;
			__bit left=0, right=0, left_q=0, right_q=0;
			KEY_ROT1(k_ra, k_rb,  !P17, !P16,  500*4/1000, left, right) // 4ms	
			KEY_QUICK(n_rot_left_q, left, left_q, 500UL*100/1000) // 100ms
			KEY_QUICK(n_rot_right_q, right, right_q, 500UL*100/1000) //100ms
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

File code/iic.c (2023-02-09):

// Copyright 2003 m24h, see http://www.apache.org/licenses/LICENSE-2.0

#include "iic.h"

// init IIC as master, spd should be ((FOSC/2/IIC_FREQ)-4)/2
void iic_init(u8 spd)
{
	I2CMSCR &= 0b01110000;  // no intr., no command now
	I2CMSAUX &= 0b11111110;  // no auto-send
	I2CCFG = 0b11000000 | spd;  // enabled as master, bus speed=Fosc/2/(x*2+4) 
	I2CMSST &= 0b00111100; // clear status
}

// wait IIC command OK	
void iic_wait ()
{
	while (!(I2CMSST & 0b01000000)); 
	I2CMSST &= 0b10111111;
}

// send IIC START, device address, wait for ACK
void iic_start(u8 dev)
{
	I2CTXD = dev;                               
	I2CMSCR = (I2CMSCR & 0b01110000) | 0b00001001;                            
	iic_wait();
}

// send IIC STOP
void iic_stop()
{
	I2CMSCR = (I2CMSCR & 0b01110000) | 0b00000110;
	iic_wait();
}

// send an IIC 8bit data
void iic_send(u8 dat)
{
	I2CTXD = dat;                               
	I2CMSCR = (I2CMSCR & 0b01110000) | 0b00001010;                            
	iic_wait();
}

// receive an IIC 8bit data and send ACK
u8 iic_recv_ack()
{
	I2CMSCR = (I2CMSCR & 0b01110000) | 0b00001011;                             
	iic_wait();
	return I2CRXD;
}

// receive an IIC 8bit data and send NAK, means it's the last data need
u8 iic_recv_nak()
{
	I2CMSCR = (I2CMSCR & 0b01110000) | 0b00001100;                             
	iic_wait();
	return I2CRXD;
}
